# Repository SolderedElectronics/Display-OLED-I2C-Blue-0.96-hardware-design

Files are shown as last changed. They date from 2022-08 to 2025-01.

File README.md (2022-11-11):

# Display OLED I2C Blue 0.96" SSD1306 Hardware design

## About the product

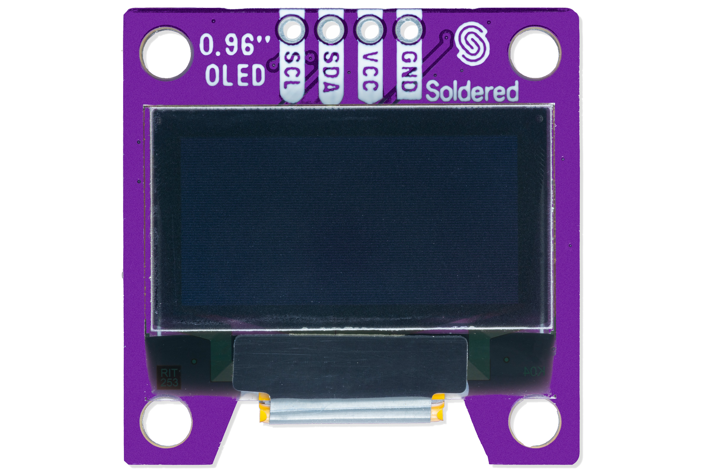
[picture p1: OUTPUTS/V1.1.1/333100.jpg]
Display OLED I2C Blue 0.96" SSD1306
|  |
| :----------------------------------------------------------: |
|      [Buy Display OLED I2C Blue 0.96" SSD1306](https://www.solde.red/333100)      |

Looking to add visuals to your Arduino projects? The I2C OLED breakout board is perfect for that. Because of its high contrast, you will be in awe of its crispness! The display is made from hundreds of LEDs, each representing one pixel in a 128x64 grid. Thus, it doesn't need any backlight, and it needs less power than the classic LCD screens. That’s 8192 pixels all individually lit at your fingertips!

The design is 5V ready with an onboard regulator, so is compatible with any 3.3V board. The breakout board uses only about 20 mA, depending on active pixels. It is easy to control over the I2C interface. It is even easier to connect with the easyC system - no soldering required!

## Repository contents

All Soldered Electronics hardware designed in KiCAD, and repositories are organized in the following way:

- CAD folder - contains KiCAD files (Schematics, Board, Panel Board), sorted by version. Change log lists all changes between versions.
- OUTPUTS - contains useful files, such as Bill of Materials (BOM), PDF of schematics, 3D .step file of the board and gerber files, sorted by version. 
- OUTPUTS -> Compliance - Certificates and useful legal stuff. 

## Want to contribute?

Please feel free to submit a pull request if you have any contributions. We encourage you to submit an issue or pull request if you find a bug. 

## About Soldered

soldered-logo

At Soldered, we design and manufacture a wide selection of electronic products to help you turn your ideas into acts and bring you one step closer to your final project. Our products are intented for makers and crafted in-house by our experienced team in Osijek, Croatia. We believe that sharing is a crucial element for improvement and innovation, and we work hard to stay connected with all our makers regardless of their skill or experience level. Therefore, all our products are open-source. Finally, we always have your back. If you face any problem concerning either your shopping experience or your electronics project, our team will help you deal with it, offering efficient customer service and cost-free technical support anytime. Some of those might be useful for you:

- [Web Store](https://www.soldered.com/shop)
- [Tutorials & Projects](https://soldered.com/learn)
- [Community & Technical support](https://soldered.com/community)

## License info

All Soldered open-source hardware (OSH) is under The TAPR Open Hardware License. Read more in the LICENSE file. 

No warranty - all designs in this repository are distributed in the hope that they will be useful, but without any warranty. They are provided "AS IS", therefore without warranty of any kind, either expressed or implied. The entire quality and performance of what you do with the contents of this repository are your responsibility. In no event, Soldered Electronics will be liable for your damages, losses, including any general, special, incidental or consequential damage arising out of the use or inability to use the contents of this repository. 

## Have fun! 
And thank you from your fellow makers at Soldered Electronics.

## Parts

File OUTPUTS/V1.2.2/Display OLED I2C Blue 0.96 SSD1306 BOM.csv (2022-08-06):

Id | Designator | Package | Quantity | Designation | Supplier and ref
1 | ,,,,,,,,,,,,,,,,,,, | buzzardLabel | 20
2 | H1,H2,H3,H4 | HOLE_3.2mm | 4 | HOLE_3.2mm
3 | R3,R7,R8,R6,R1,R4,R2 | 0603R | 7 | 10k
4 | JP6,JP5 | SMD_JUMPER | 2 | SMD_JUMPER
5 | C7,C3,C9 | 1206C | 3 | 10u
6 | R5 | 0402R | 1 | 2k2
7 | R9 | 0603R | 1 | 390k
8 | FD1 | FIDUCIAL_23 | 1 | FIDUCIAL
9 | K3 | HEADER_MALE_4X1 | 1 | HEADER_MALE_4X1
10 | D1 | 0402LED | 1 | purple
11 | C1,C8,C2,C5 | 0603C | 4 | 2u2
12 | G***,G*** | Logo-Front-easyC-5mm | 2 | LOGO
13 | U1 | SOT-363 | 1 | NMOS-DUAL
14 | JP1,JP3 | SMD_JUMPER_3_PAD_TRACE | 2 | SMD_JUMPER_3_PAD_TRACE
15 | REF** | Symbol-Front-I2C-ADDR-Field | 1 | Symbol-Front-I2C-ADDR-Field
16 | K2,K1 | easyC-connector | 2 | easyC-SMD
17 | JP4,JP2 | SMD-JUMPER-CONNECTED_TRACE_SLODERMASK | 2 | SMD-JUMPER-CONNECTED_TRACE_SLODERMASK
18 | U3 | OLED_GME128x64_30p | 1 | OLED_GME12864_30p
19 | C10,C6 | 0603C | 2 | 100n
20 | G*** | Logo-Back-SolderedVERTICAL-6mm | 1 | LOGO
21 | G*** | Logo-Front-Soldered-4mm | 1 | LOGO
22 | G*** | Logo-Front-OSH-3.5mm | 1 | LOGO
23 | REF** | Version1.1.1. | 1 | Version1.1.1.
24 | C4 | 0603C | 1 | 1u
25 | U2 | SOT-23-5 | 1 | SE5218

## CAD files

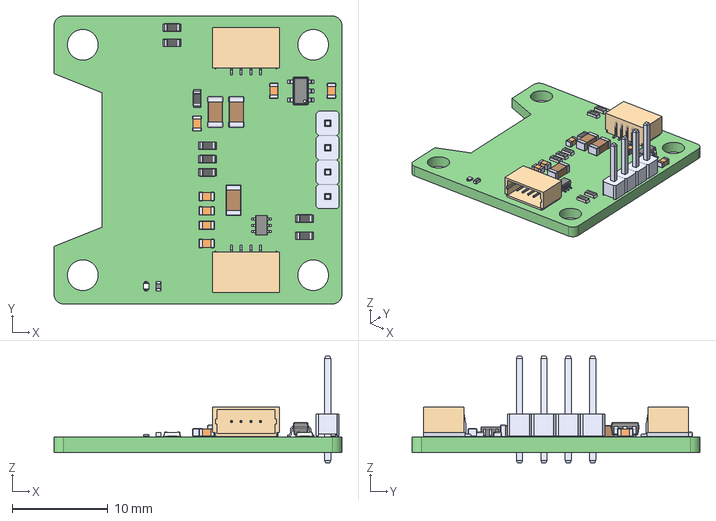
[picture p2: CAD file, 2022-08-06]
OUTPUTS/V1.2.2/Display OLED I2C Blue 0.96 SSD1306 3D.step
30.0 x 30.0 x 11.1 mm

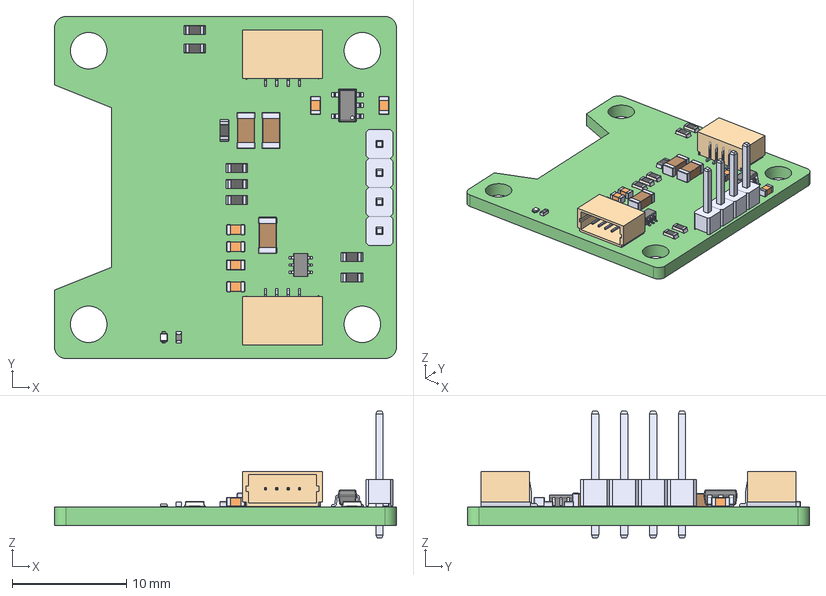
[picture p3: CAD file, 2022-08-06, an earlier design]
OUTPUTS/V1.1.1/OLED_0-96_3D.step
30.0 x 30.0 x 11.1 mm

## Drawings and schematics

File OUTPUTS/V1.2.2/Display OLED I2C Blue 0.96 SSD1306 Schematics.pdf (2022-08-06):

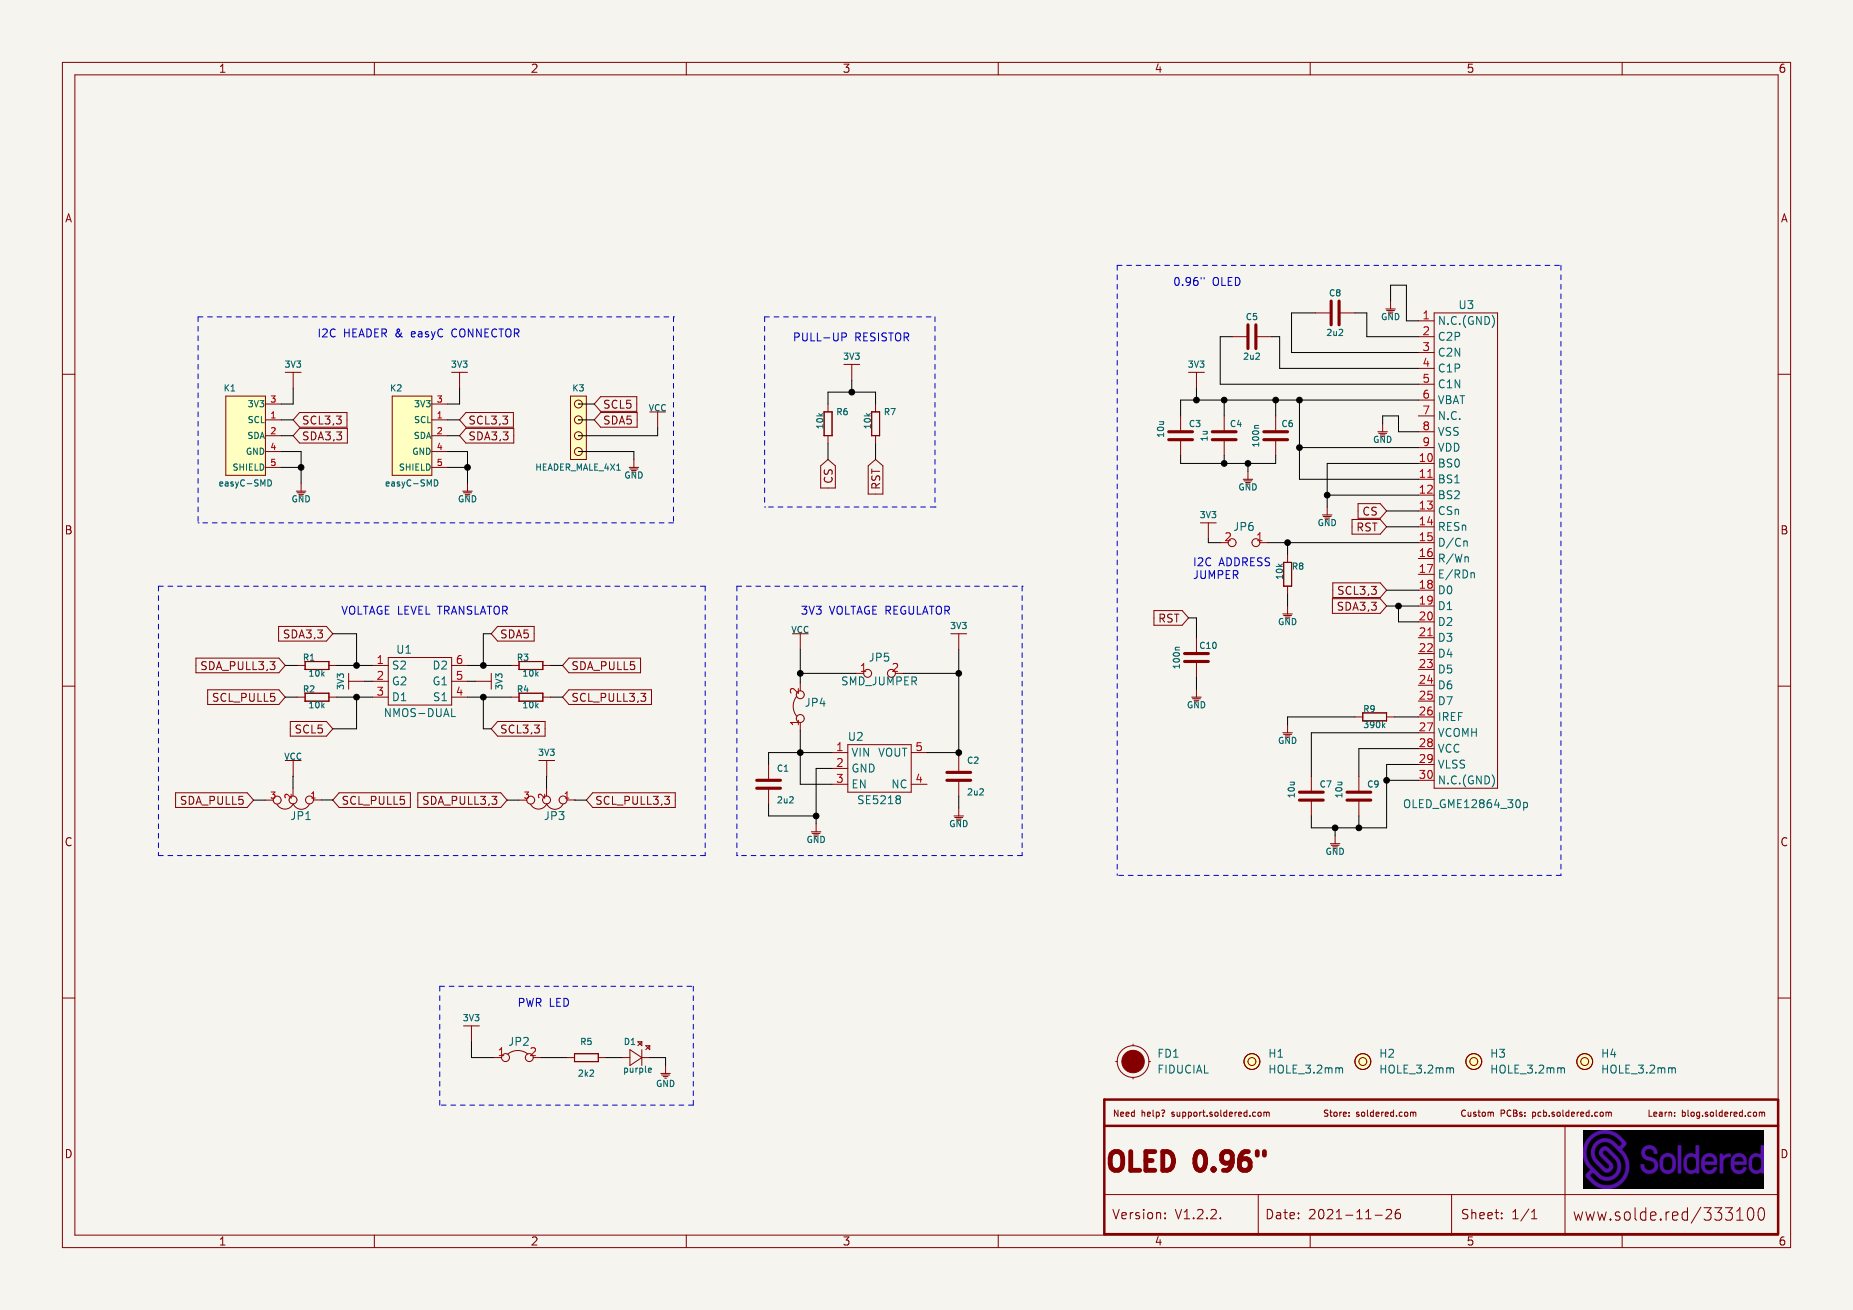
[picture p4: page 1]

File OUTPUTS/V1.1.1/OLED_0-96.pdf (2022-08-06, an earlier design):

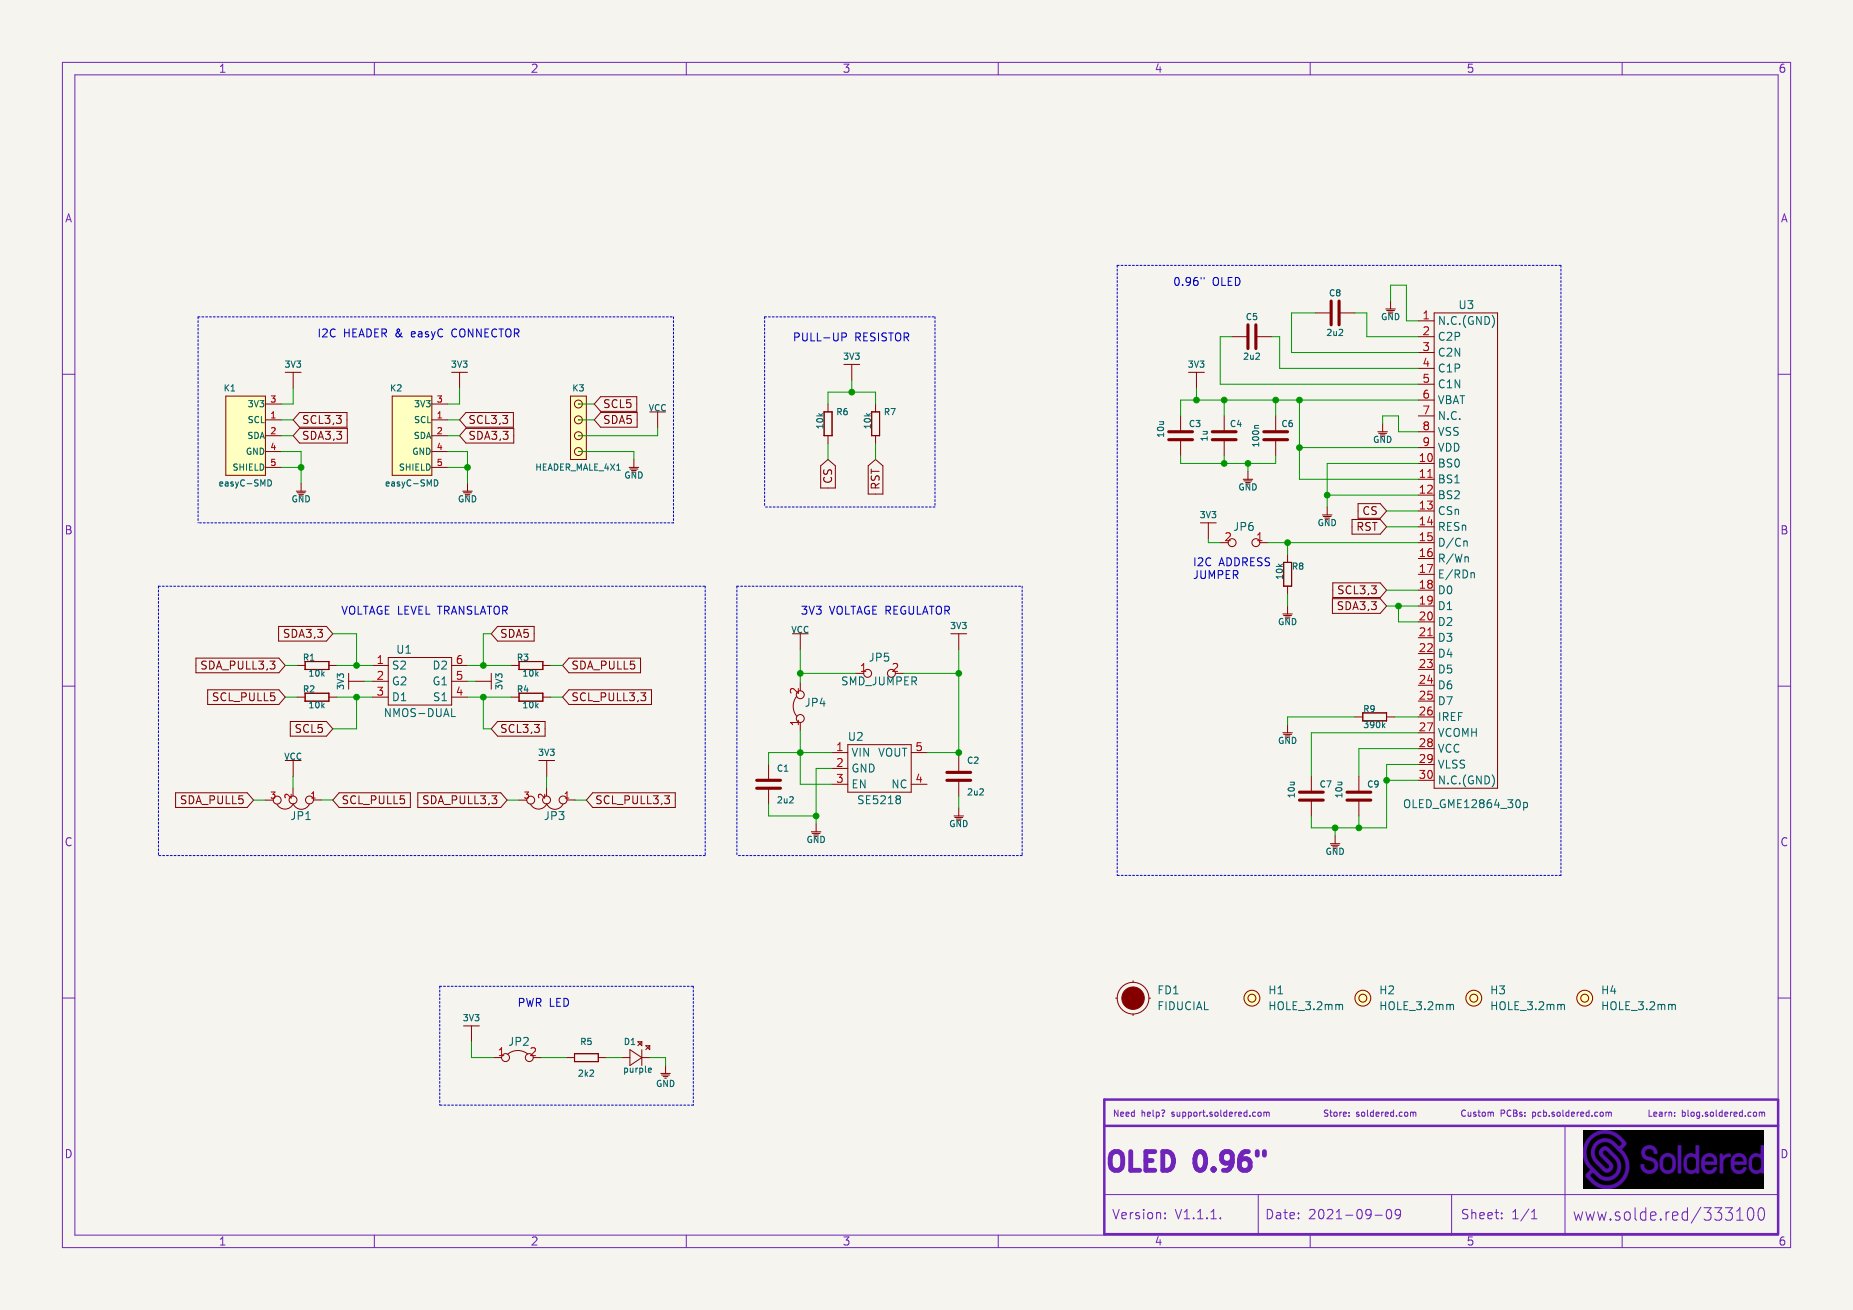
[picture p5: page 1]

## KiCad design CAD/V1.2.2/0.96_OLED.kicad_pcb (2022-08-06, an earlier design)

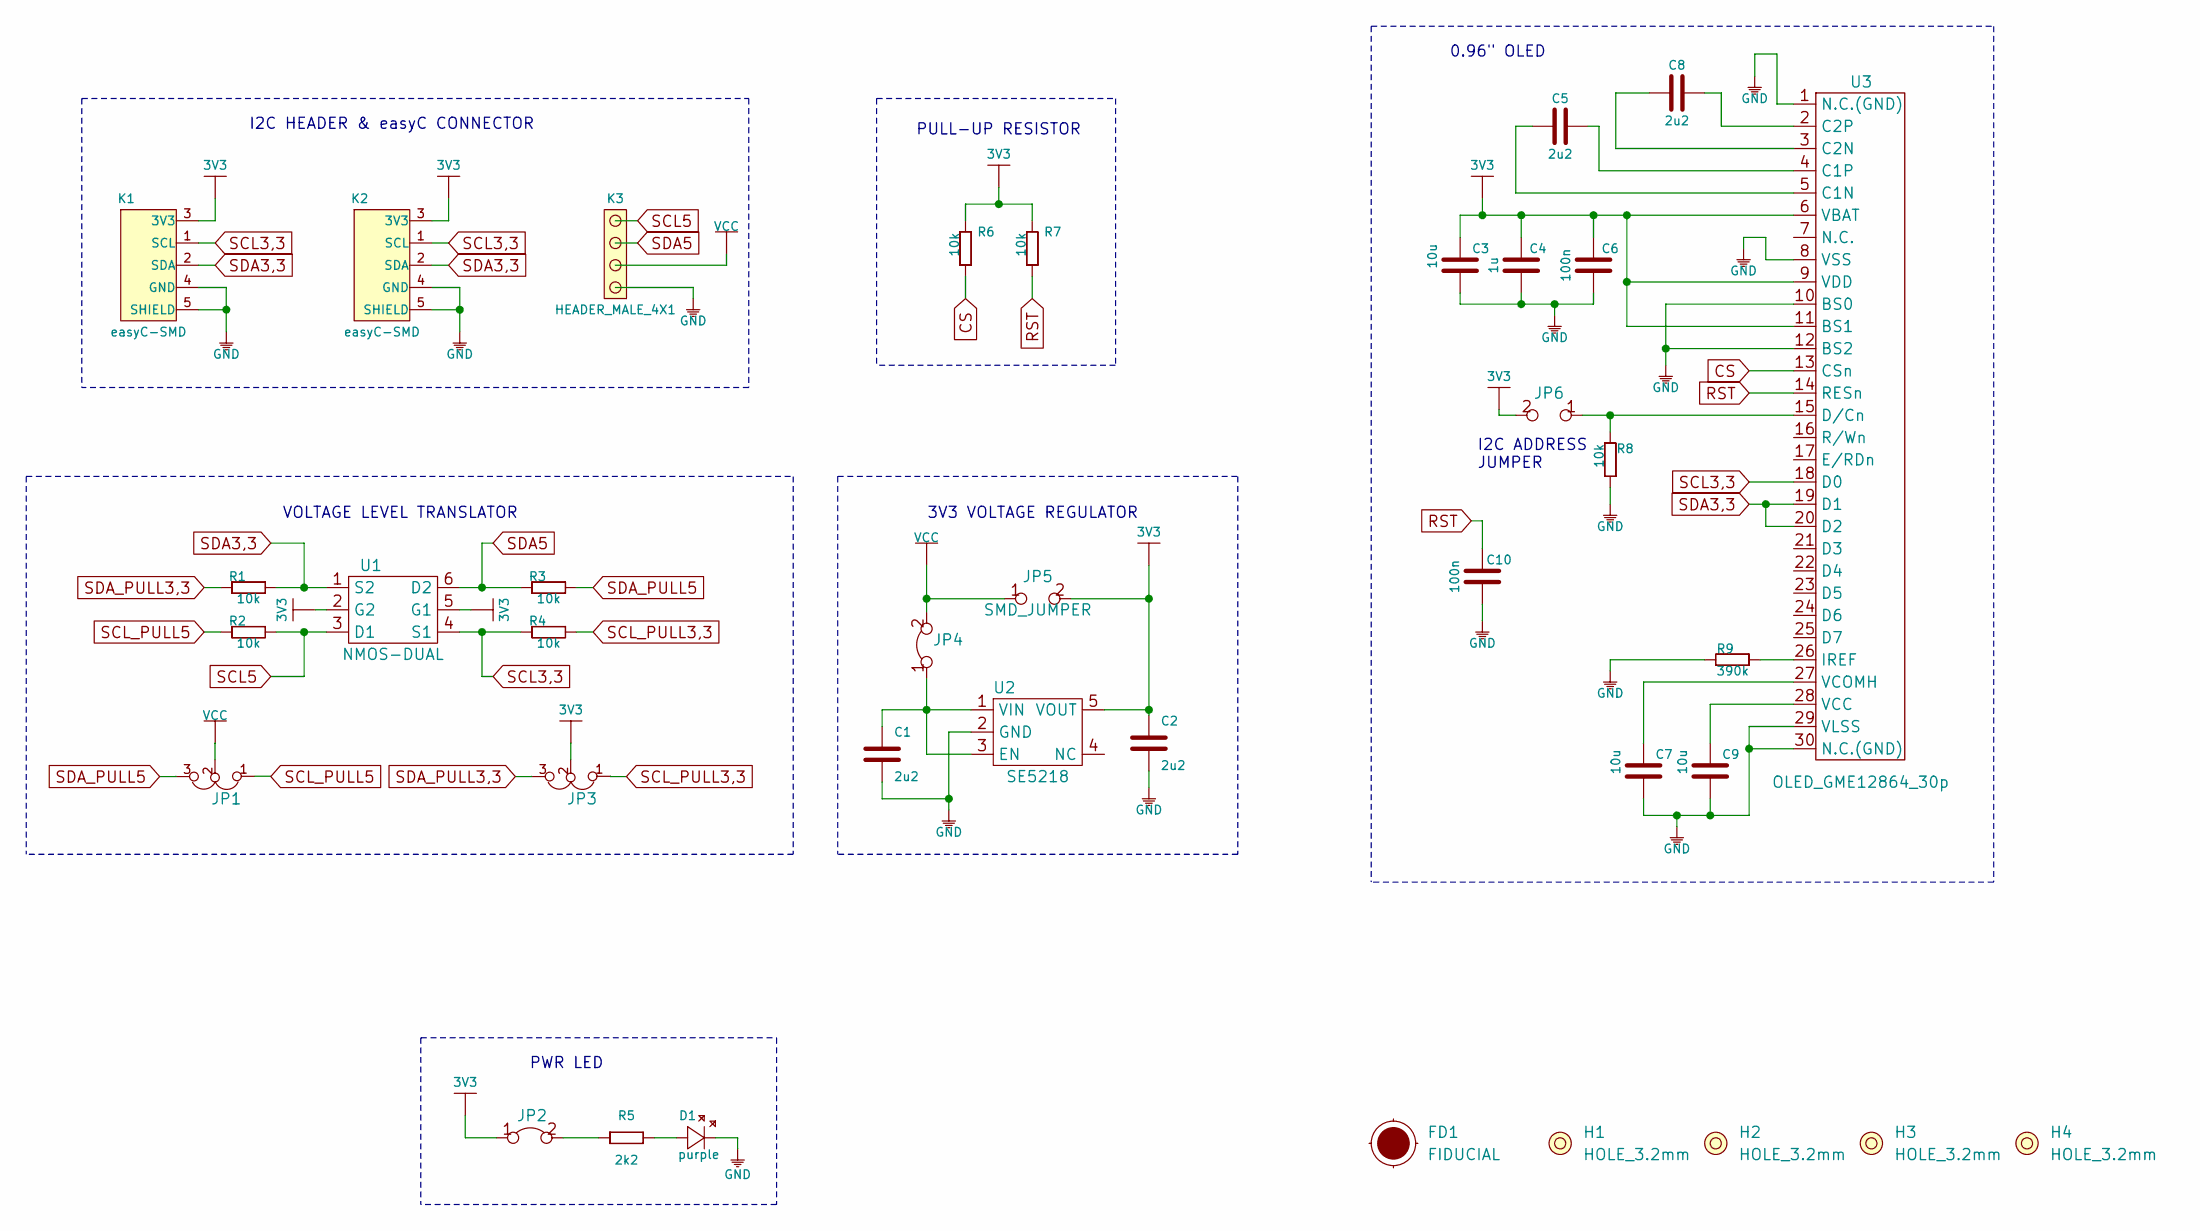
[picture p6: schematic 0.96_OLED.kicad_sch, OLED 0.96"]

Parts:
C1, C2, C5, C8: 2u2; 0603C
C3, C7, C9: 10u; 1206C
C4: 1u; 0603C
C6, C10: 100n; 0603C
D1: purple; 0402LED
FD1: FIDUCIAL; FIDUCIAL_23
H1, H2, H3, H4: HOLE_3.2mm
JP1, JP3: SMD_JUMPER_3_PAD_TRACE
JP2, JP4: SMD-JUMPER-CONNECTED_TRACE_SLODERMASK
JP5, JP6: SMD_JUMPER
K1, K2: easyC-SMD; easyC-connector
K3: HEADER_MALE_4X1
R1, R2, R3, R4, R6, R7, R8: 10k; 0603R
R5: 2k2; 0402R
R9: 390k; 0603R
U1: NMOS-DUAL; SOT-363
U2: SE5218; SOT-23-5
U3: OLED_GME12864_30p; OLED_GME128x64_30p

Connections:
3V3: C2.2, C3.1, C4.1, C6.1, JP2.1, JP3.2, JP5.2, JP6.2, K1.3 (3V3), K2.3 (3V3), R6.2, R7.2, U1.2 (G2), U1.5 (G1), U2.5 (VOUT), U3.6 (VBAT), U3.9 (VDD), U3.11 (BS1)
CS: R6.1, U3.13 (CSn)
GND: C1.1, C2.1, C3.2, C4.2, C6.2, C7.2, C9.2, C10.2, D1.2 (K), K1.4 (GND), K1.5 (SHIELD), K2.4 (GND), K2.5 (SHIELD), K3.1, R8.1, R9.2, U2.2 (GND), U3.1 (N.C.(GND)), U3.8 (VSS), U3.10 (BS0), U3.12 (BS2), U3.29 (VLSS), U3.30 (N.C.(GND))
unnamed: C1.2, JP4.1, U2.1 (VIN), U2.3 (EN)
unnamed: C5.1, U3.5 (C1N)
unnamed: C5.2, U3.4 (C1P)
unnamed: C7.1, U3.27 (VCOMH)
unnamed: C8.1, U3.3 (C2N)
unnamed: C8.2, U3.2 (C2P)
unnamed: C9.1, U3.28 (VCC)
unnamed: D1.1 (A), R5.2
unnamed: JP2.2, R5.1
unnamed: JP6.1, R8.2, U3.15 (D/Cn)
unnamed: R9.1, U3.26 (IREF)
RST: C10.1, R7.1, U3.14 (RESn)
SCL3,3: K1.1 (SCL), K2.1 (SCL), R4.1, U1.4 (S1), U3.18 (D0)
SCL5: K3.4, R2.2, U1.3 (D1)
SCL_PULL3,3: JP3.1, R4.2
SCL_PULL5: JP1.1, R2.1
SDA3,3: K1.2 (SDA), K2.2 (SDA), R1.2, U1.1 (S2), U3.19 (D1), U3.20 (D2)
SDA5: K3.3, R3.1, U1.6 (D2)
SDA_PULL3,3: JP3.3, R1.1
SDA_PULL5: JP1.3, R3.2
VCC: JP1.2, JP4.2, JP5.1, K3.2

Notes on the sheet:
0.96" OLED
3V3 VOLTAGE REGULATOR
I2C ADDRESS JUMPER
I2C HEADER & easyC CONNECTOR
PULL-UP RESISTOR
VOLTAGE LEVEL TRANSLATOR
PWR LED

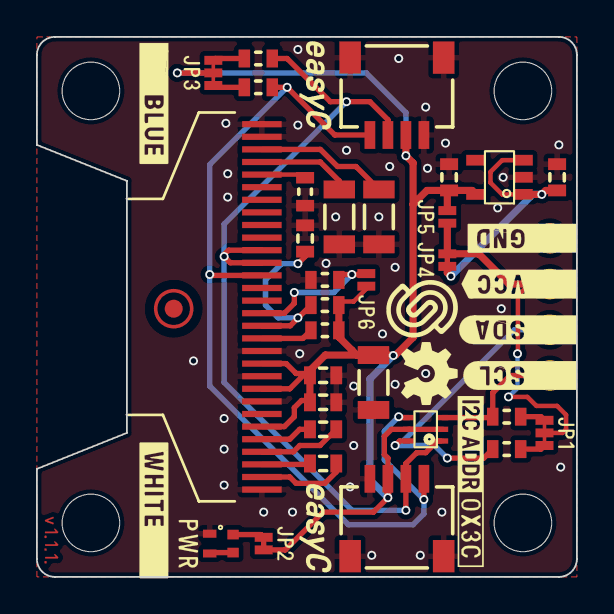
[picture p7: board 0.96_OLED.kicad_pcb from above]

Board: 2 copper layers, 30.0 x 30.0 mm, 37 parts (0 on the bottom side), 24 nets.

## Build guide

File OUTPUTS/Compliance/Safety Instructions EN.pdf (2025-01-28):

PLEASE RETAIN THIS INFORMATION FOR FUTURE REFERENCE.

BEFORE USING THIS PRODUCT, READ ALL INSTRUCTION IN THIS DOCUMENT.

Product name: Display OLED I2C Blue 0.96" SSD1306
Getting started: To get started, please visit www.soldered.com

## WARNINGS

- This product should not be covered and should be operated in well ventilated enviroment.
- The product should be placed on a stable, flat, non-conductive surface and should not be contacted by conductive items.
- Connection of other devices may affect compliance or result in damage to the unit, and invalidate the warranty.
- Where peripherals are connected that do not include the cable or connector, the cable or connector used must offer adequate insulation and operation in order that the requirements of the relevant performance and safety requirements are met.
- There is a danger of explosion if the battery is incorrectly placed.
- The product should not be used outside of its specified working range.

## INSTRUCTIONS FOR SAFE USE

To avoid malfunction or damage to your device, please observe the following:
- Do not expose it to water, moisture or place on a conductive surface when turned on. Do not handle the unit with wet hands.
- Do not expose it to heat from any source; the product is designed to be used at normal ambient room temperatures. The product is intended to be used inside.
- Take care when handling to avoid mechanical or electrical damage to any part of the unit. Avoid handling the unit while it's powered. Use ESD protection.
- Use only supplied cable (or the cable of the same or higher quality) with the unit.

## COMPLIANCE INFORMATION

The product complies with the relevant provision of the RoHS Directive for the European Union. In common with all Electrical and Electronic Equipment (EEE), the product should not be disposed household waste.

ELECTROMAGNETIC COMPABILITY AND OPERATION

- The product is in conformity with the protection requirements of EU Council Directive 2014/30/EU on the laws of the Member States relating of electromagnetic compability, and Electromagnetic Compability Regulations 2016 of the UK.
- WARNING: Please do not alter the design of this product, doing so may void your ability to use the product freely, this includes altering the frequency at which product operates.

### Regulatory Compliance and Important Safety Information

Soldered Electronics d.o.o., Vinkovačka cesta 68, 31000 Osijek, Croatia. VAT ID: HR83200237288

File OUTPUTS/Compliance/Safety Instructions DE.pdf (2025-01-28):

BITTE BEWAHREN SIE DIESE INFORMATIONEN ZUR SPÄTEREN VERWENDUNG AUF.
LESEN SIE VOR DER VERWENDUNG DIESES PRODUKTS ALLE ANWEISUNGEN IN DOKUMENT. Produktname: Display OLED I2C Blue 0.96" SSD1306
Die ersten Schritte:Besuchen Sie www.soldered.com, um loszulegen.

## WARNUNGEN

- Dieses Produkt sollte nicht abgedeckt werden und in einer gut belüfteten Umgebung betrieben werden.
- Das Produkt sollte auf einer stabilen, flachen, nicht leitenden Oberfläche aufgestellt werden und nicht mit leitenden Gegenständen in Berührung kommen.
- Der Anschluss anderer Geräte kann die Konformität beeinträchtigen oder zu Schäden am Gerät führen und zum Erlöschen der Garantie führen.
- Wenn Peripheriegeräte angeschlossen werden, die nicht das Kabel oder den Stecker enthalten, muss das verwendete Kabel oder muss das verwendete Kabel bzw. der verwendete Steckverbinder eine angemessene Isolierung und Funktion aufweisen, damit die Anforderungen die einschlägigen Leistungs- und Sicherheitsanforderungen erfüllt werden.
- Es besteht Explosionsgefahr, wenn die Batterie falsch eingesetzt wird.
- Das Produkt sollte nicht außerhalb des angegebenen Arbeitsbereichs verwendet werden.

## HINWEISE ZUR SICHEREN ANWENDUNG

Um Fehlfunktionen oder Schäden an Ihrem Gerät zu vermeiden, beachten Sie bitte die folgenden Hinweise:
- Setzen Sie das Gerät nicht Wasser oder Feuchtigkeit aus und stellen Sie es nicht auf eine
leitende Oberfläche, wenn es eingeschaltet ist. Das Gerät nicht mit nassen Händen anfassen.
- Setzen Sie es keiner Wärmequelle aus; das Produkt ist für die Verwendung bei normalen Raumtemperaturen ausgelegt. Das Produkt ist für die Verwendung in Innenräumen vorgesehen.
- Seien Sie bei der Handhabung vorsichtig, um mechanische oder elektrische Schäden an Teilen des Geräts zu vermeiden. Fassen Sie das Gerät nicht an, wenn es unter Spannung steht. Verwenden Sie einen ESD-Schutz.
- Verwenden Sie nur das mitgelieferte Kabel (oder ein gleich- oder höherwertiges Kabel)
mit dem Gerät.

## COMPLIANCE-INFORMATIONEN

Das Produkt entspricht den entsprechenden Bestimmungen der RoHS-Richtlinie für die Europäische Union. Wie alle elektrischen und elektronischen Geräte (EEE), sollte das Produkt nicht über den Hausmüll entsorgt werden.
ELEKTROMAGNETISCHE VERTRÄGLICHKEIT UND BETRIEB
- Das Produkt entspricht den Schutzanforderungen der Richtlinie des EU-Rates 2014/30/EU über die Rechtsvorschriften der Mitgliedstaaten zur elektromagnetischen Verträglichkeit und den Elektromagnetische Verträglichkeitsverordnung 2016 des Vereinigten Königreichs.
- WARNUNG: Bitte verändern Sie nicht das Design dieses Produkts, da dies dazu führen kann, dass Sie das Produkt nicht mehr uneingeschränkt nutzen können.
Dies gilt auch für die Änderung der Frequenz, mit der das Produkt arbeitet.

## Einhaltung gesetzlicher Vorschriften und wichtige

Soldered Electronics d.o.o., Vinkovačka cesta 68, 31000 Osijek, Croatia. VAT ID: HR83200237288

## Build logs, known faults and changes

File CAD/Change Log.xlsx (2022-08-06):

CHANGE LOG
 | Latest version |  |  | v1.2.2.
 |  | Product name: |  | Display OLED I2C Blue 0.96
 |  | Release date: |  | 26.11.2021.
 |  | Release author: |  | Ivan Fadiga
Version: | v1.0.0. | Author: | Ivan Fadiga | Date: | 16.8.2021.
List of Changes
 | Initial document
Version: | V1.1.1 | Author: | Ivan Fadiga | Date: | 9.9.2021.
List of Changes
 | Changed I2C address
 | Changed label for I2C address
 | Changed color options (BLUE and WHITE)
Version: | V1.2.2. | Author: | Ivan Fadiga | Date: | 26.11.2021.
List of Changes
 | Added 100nF capacitor between RST and GND
